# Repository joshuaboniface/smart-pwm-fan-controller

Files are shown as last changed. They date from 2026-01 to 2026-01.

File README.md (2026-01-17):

# Smart PWM Fan Controller v1.x

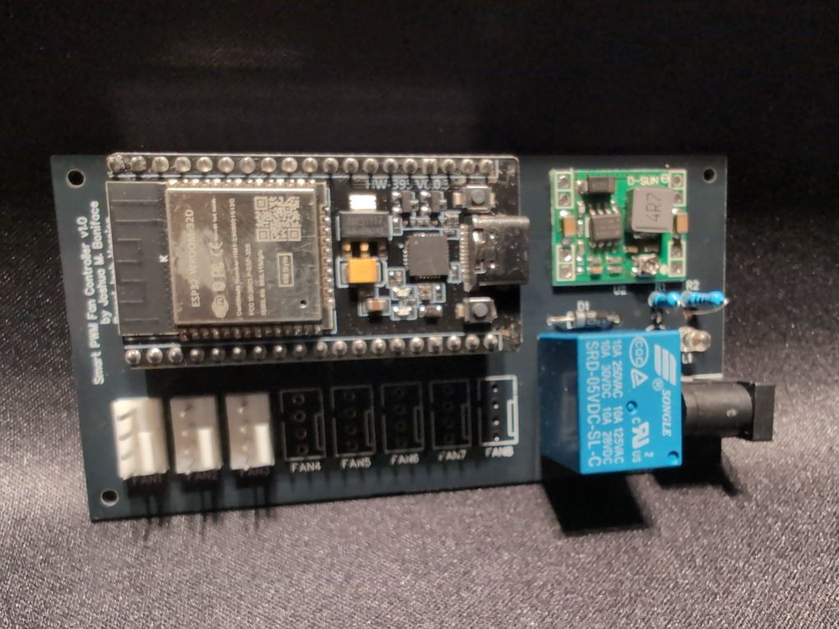
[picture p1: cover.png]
Fan Controller


The Smart PWM Fan Controller is a 4-pin 12V PWM PC fan controller (as the name implies) based on the ESP32 HW-395 form-factor and running ESPHome, and powered by a 12VDC barrel jack or 12V EPS (CPU) connector (ensure you pick the right board design).

It can connect up to 8 fans directly, with the following functionality:

 * Bank on/off via relay.
 * Bank PWM control (0-100%) via ESP32 GPIO.
 * Individual fan RPM monitoring (2PPM) via ESP32 PCNT.
 * Bank fault detection via settable fan count and RPM detection (an expected-present fan with 0 RPM while on is a fault).

The PCB design details and assembly instructions can be found [in /board](board/) and on [OSHWLab](https://oshwlab.com/joshuaboniface/microenv-2-0).

For full details, [please see my blog post on the project](https://www.boniface.me/posts/smart-pwm-fan-controller).

## Parts List

**Note:** All prices are $CAD, as of May 2025, excluding shipping, sales, and bulk discounts beyond those indicated.

**Note:** For AliExpress item links marked `*`, ensure you select the correct device; multiple different models share the page.

**Note:** Several pieces came as part of larger variety kits, so individual prices may not be completely accurate.

| Qty | PCB ID(s) | Component | Cost | Links |
|---|---|---|---|---|
| 1 | N/A | Custom PCB (JLC) | $0.50 ($5.00/10) | [GitHub](https://github.com/joshuaboniface/esphome-pwm-fan-controller) |
| 1 | U1 | ESP32 HW-395 | $6.67 | [AliExpress](https://www.aliexpress.com/item/1005006019875837.html)* |
| 8 | FANX | 4-pin fan header | $0.21 ($1.02/5) | [AliExpress](https://www.aliexpress.com/item/1005007499957251.html) |
| 1 | U2 | MP1584EN DC-DC converter  | $1.34 ($13.99/10) | [Amazon](https://www.amazon.ca/dp/B07THSDWHX) (variable output) |
| 1 | U4 | SRD-05VDC-SL-C relay | $1.52 ($18.16/12) | [Amazon](https://www.amazon.ca/dp/B098JHY5TP) |
| 1 | U3 | DC barrel jack | $0.98 ($9.79/10) | [Amazon](https://www.amazon.ca/dp/B011HFLKI2) |
| 2 | R1/R2 | 1kΩ resistor (1%) | $0.06 ($10.99/200) | [Amazon](https://www.amazon.ca/dp/B096PK4XN5) |
| 1 | D1 | 1N4004 diode | $0.07 ($20.99/300) | [Amazon (kit)](https://www.amazon.ca/dp/B07YK3XMQQ) |
| 1 | Q1 | BC337 transistor | $0.06 ($12.13/200) | [Amazon (kit)](https://www.amazon.ca/dp/B07X62PBMH) |
| 1 | L1 | 3mm LED | $0.05 ($15.99/350) | [Amazon (kit)](https://www.amazon.ca/dp/B073GRZNRL) |
| 2 | N/A | 2.54mm 1x19 female header | $0.31 ($3.14/10) | [AliExpress](https://www.aliexpress.com/item/4001198421663.html)* |
| **T** | | | $13.30 | |

# Contributing

If you wish to contribute to the MicroEnv project, please open a pull request in this repository. All pull requests will be carefully reviewed before inclusion, as we are extremely selective about what we modify. Note that any signifiant logical changes should also be compatible with the SuperSensor, and changes from that project will be occasionally integrated here.

Please ensure you target the correct branch(es) for your changes. Currently we are supporting both `v1.x` and `v2.x` in software as noted above, and there is no `master`/`main` branch. This support of both `v1.x` and `v2.x` means a 1-to-1 correlation of functionality between those two versions, so any PR to one will be back- or forward-ported to the other, and your changes(s) must be compatable with both.

Any changes must be **globally applicable to all users** of the project; if you wish to maintain your own customizations that are only applicable for yourself, please fork the project and adjust your package import URL accordingly.

"AI" (LLM) contributions are not prohibited, but you - a human - **must** at least review, reformat, and test the changes yourself before submitting them. Obviously pure-LLM-generated PRs that do not function, mangle formatting or functionality, or otherwise clearly have no human review will be rejected with prejudice. This extends to the PR body itself: write in your own words, not the output of an LLM, and if you can't concisely sumarize the changes yourself, then we're not interested in them.

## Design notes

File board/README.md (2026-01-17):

# Smart PWM Fan Controller v1.x Board Designs

This is a collection of [EasyEDA](https://easyeda.com/) schematics and board desgins for the Smart PWM Fan Controller v1.x's components.

You can import the design definition files (`*.easyeda.json`) directly into EasyEDA via "File" -> "Open" -> "EasyEDA". The schematic is provided for reference in both EasyEDA and SVG formats; if you just wish to manufacture the boards, you only need to import the board definitions, then via "Fabrication" -> "One-click Order PCB/SMT" complete the order at [JLCPCB](https://jlcpcb.com). We order all boards in a black silkscreen with all other options as default.

You can also see the designs directly on [OSHWLab here](https://oshwlab.com/joshuaboniface/smart-pwm-fan-controller-1-0).

The board design and images in this folder are © 2025 [Joshua M. Boniface](https://www.boniface.me) and licensed under the [Creative Commons Attribution-ShareAlike (BY-SA) 4.0](LICENSE) license.

## Schematic

The schematic is visible here in SVG format, and also as an EasyEDA definition in [schematic.easyeda.json](schematic.easyeda.json).

Design schematic

The individual parts can be found, with their labels (`R1`, etc.) in the [main README parts list](https://github.com/joshuaboniface/smart-pwm-fan-controller/?tab=readme-ov-file#parts-list).

## Board

Smart PWM Fan Controller v1.x board

This is the main board of the controller which contains all components.

The board is single-sided; there are no components on the reverse side, though most components are through-hole.

## Assembly

**NOTE:** The assembly step ordering is **extremely important** if you are using a **variable 12VDC-to-5VDC converter**! You must calibrate it before attaching most components, or can risk frying them.

Assembly is fairly straightforward aside from the ordering. Most of the soldering should be done with a standard soldering iron, though hot air or a hotplate can make attaching the MP1584EN easier.

1. Clean all PCBs thoroughly with isopropyl alcohol and paper towel.

2. If using hot air or a hotplate for the MP1584EN, apply a liberal amount of solder paste to each pad.

3. Solder the MP1584EN onto the board using the desired method.

4. Solder the barrel jack (or Molex connector) onto the board.

5. Perform calibration of the MP1584EN. Plug in a 12VDC source, and turn the adjustment screw until a multimeter on the output ports reads ~5.05VDC.

6. Solder the remaining components onto the board. We tend to start with the smaller components (Q1, L1, R1/R2, D1) then move onto the larger components (U4, U1, FANX).

5. Perform electrical continuity tests to ensure there are no stray bridges or faulty connections.

The Smart PWM Fan Controller is now fully assembled and ready for final testing/provisioning.

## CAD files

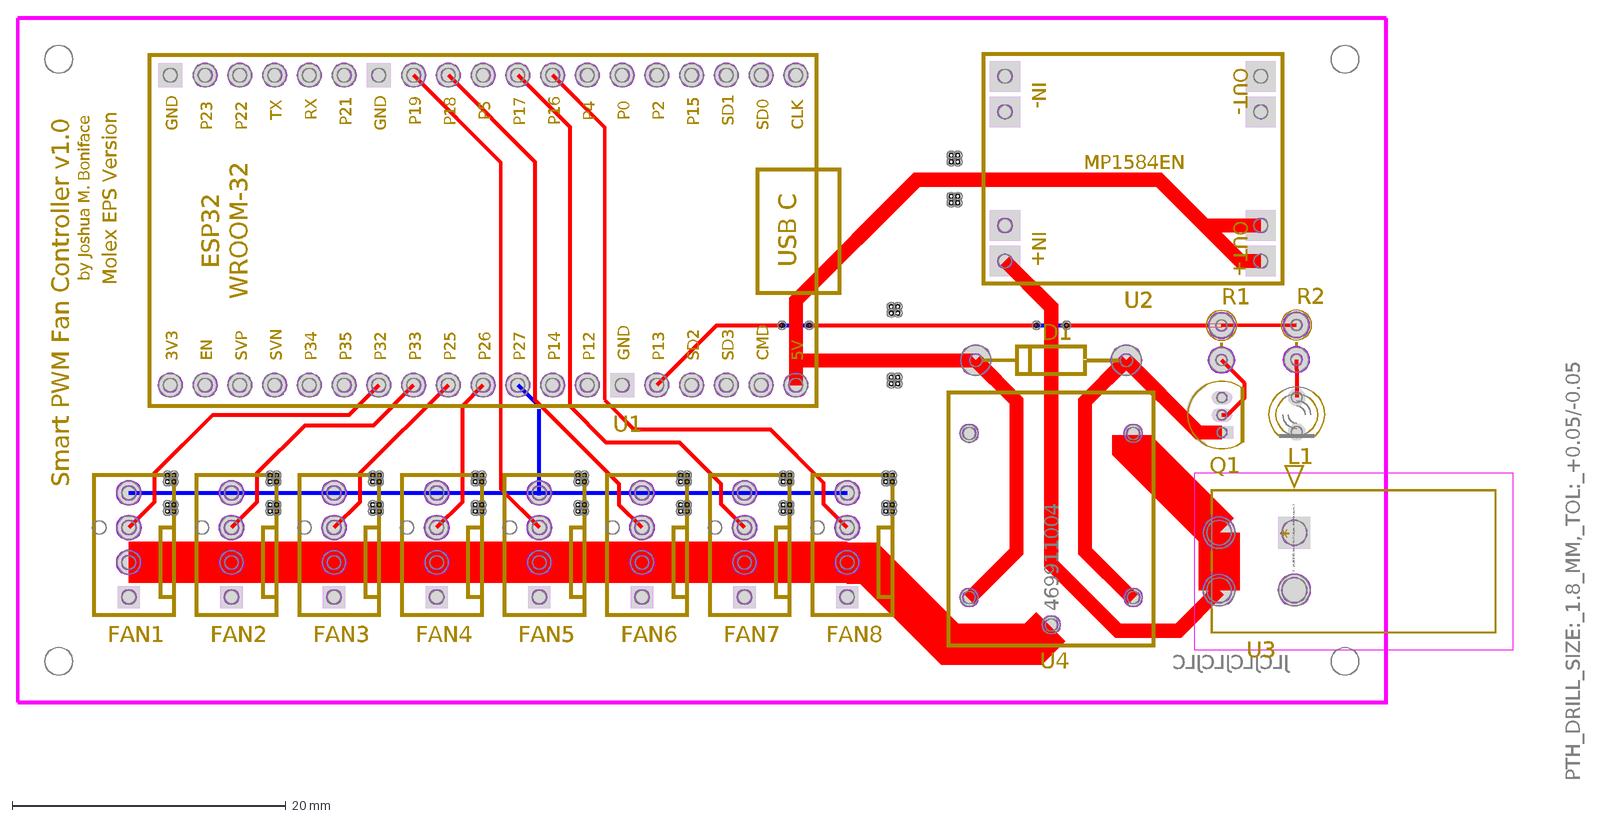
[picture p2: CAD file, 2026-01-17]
board/fan-controller-molex-eps.dxf
JLCJLCJLCJLC
Smart PWM Fan Controller v1.0
by Joshua M. Boniface
Molex EPS Version
U3
Copyright 2021 Accelerated Designs. All rights reserved.
*
469911004
PTH_DRILL_SIZE:_1.8_MM,_TOL:_+0.05/-0.05
D1
L1
Q1
R1
R2
U2
OUT-
OUT+
IN-
IN+
MP1584EN
U4
U1
3V3
EN
SVP
SVN
P34
P35
P32
P33
P25
P26
P27
P14
P12
GND
P13
SD2
SD3
CMD
5V
P23
P22
TX
RX
P21
P19
P18
P5
P17
P16
P4
P0
P2
P15
SD1
SD0
CLK
ESP32
WROOM-32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

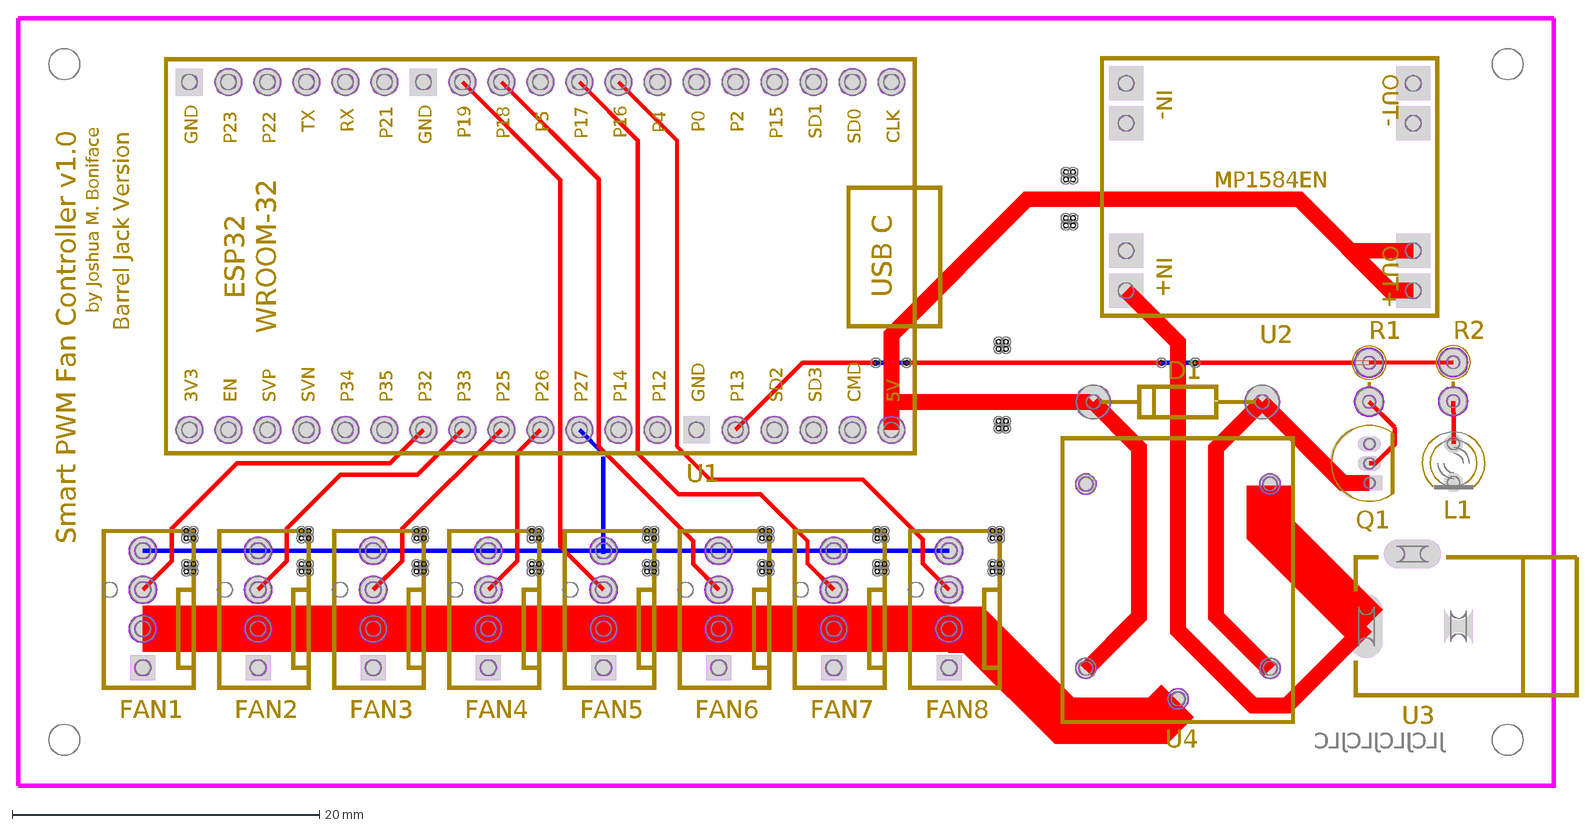
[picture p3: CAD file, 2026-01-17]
board/fan-controller-barrel-jack.dxf
JLCJLCJLCJLC
Barrel Jack Version
by Joshua M. Boniface
Smart PWM Fan Controller v1.0
D1
L1
Q1
R1
R2
U2
OUT-
OUT+
IN-
IN+
MP1584EN
U3
U4
U1
3V3
EN
SVP
SVN
P34
P35
P32
P33
P25
P26
P27
P14
P12
GND
P13
SD2
SD3
CMD
5V
P23
P22
TX
RX
P21
P19
P18
P5
P17
P16
P4
P0
P2
P15
SD1
SD0
CLK
ESP32
WROOM-32
USB C
FAN1
FAN2
FAN3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

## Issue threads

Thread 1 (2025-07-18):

Gerber schematic files

lubbertkramer, 2025-07-18:
Hi,

i would like to build your PCB but i don't see the GERBER Schematic files that i could add to PCBWay to let the board be builded. Are they available?

Thanks!

lubbertkramer, 2025-07-18:
Sorry oversaw the EasyAda files, made the gerber files myself. Thanks!

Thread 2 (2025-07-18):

Schematics file to add temperature sensor

lubbertkramer, 2025-07-18:
Hi,

could you also share the schematics file so i can alter your board to add a temperature sensor? I would like to use this board with 12v fans in the cabinet (PS5 / xbox) but would like to add a temperature sensor to it.

Thanks!

nebriv, 2025-08-27:
@lubbertkramer would also love to see that, any chance you have a fork?

lubbertkramer, 2025-08-27:
If @joshuaboniface has no problems with it i can share it with him so he can publish it here combined after my order has been delivered and i have checked its working as i expect it will be :)

Closed 2025-07-18.

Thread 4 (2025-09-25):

Ordering the PCB help

thomasgebets, 2025-09-25:
Hi i found your blog on the ESP32 PWM Controller and would like to replicate.
Unfortunately, i'm struggling with ordering the PCB since i have never done it and jlcpcb asks me for a gerber file?

Did you need such a file to order, could you maybe provide your order details such as pcb type etc?

Thanks for the help, appreciate it!

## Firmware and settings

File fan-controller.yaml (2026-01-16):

---

###############################################################################
# Smart PWM Fan Controller v1.0 ESPHome configuration
###############################################################################
#
#    Copyright (C) 2025 Joshua M. Boniface <joshua@boniface.me>
#
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
###############################################################################

esphome:
  name: fan-controller
  name_add_mac_suffix: true
  friendly_name: "Fan Controller"
  project:
    name: joshuaboniface.fan-controller
    version: "1.0"
  on_boot:
    priority: 200
    then:
      - script.execute:
          id: set_fan_speed
          value: !lambda 'return id(fan_speed);'

dashboard_import:
  package_import_url: github://joshuaboniface/smart-pwm-fan-controller/fan-controller.yaml@master

esp32:
  board: esp32dev
  framework:
      type: esp-idf

preferences:
  flash_write_interval: 15sec

logger:
  level: VERBOSE
  baud_rate: 115200

api:
  reboot_timeout: 15min

ota:
  platform: esphome

web_server:
  port: 80

captive_portal:

mdns:
  disabled: false

wifi:
  ap: {}
  domain: ""
  output_power: 8.5dB
  reboot_timeout: 15min
  power_save_mode: none

globals:
  - id: fan_speed
    type: float
    restore_value: true
    initial_value: '100.0'

  - id: attached_fans
    type: int
    restore_value: true
    initial_value: '0'

script:
  - id: set_fan_speed
    mode: single
    then:
      - lambda: |-
          id(fan_pwm_output).set_level(id(fan_speed) / 100.0);

number:
  - platform: template
    name: "Fan Speed"
    id: fan_speed_setter
    unit_of_measurement: "%"
    min_value: 0
    max_value: 100
    step: 1
    set_action:
      then:
        - lambda: |-
            ESP_LOGD("fan_speed", "Setting fan speed to %.1f%%", x);
            id(fan_speed) = x;
            id(fan_pwm_output).set_level(x / 100.0);
    lambda: |-
      return id(fan_speed);

  - platform: template
    name: "Attached Fans"
    id: attached_fans_setter
    icon: mdi:fan-auto
    min_value: 0
    max_value: 8
    step: 1
    set_action:
      then:
        - lambda: |-
            id(attached_fans) = x;
    lambda: |-
      return id(attached_fans);

switch:
  - platform: gpio
    name: "Fan Power"
    id: fan_power
    icon: mdi:fan
    pin: GPIO13

  - platform: template
    name: "Show Total in Fan Status"
    id: show_total_fans
    icon: mdi:ab-testing
    optimistic: true
    restore_mode: RESTORE_DEFAULT_OFF

output:
  - platform: ledc
    id: fan_pwm_output
    pin: GPIO27

button:
  - platform: restart
    name: "ESP32 Restart"
    icon: mdi:power-cycle
    entity_category: diagnostic

text_sensor:
  - platform: template
    name: "Fan Fault"
    icon: mdi:fan-alert
    update_interval: 30s
    lambda: |-
      if (!id(fan_power).state) return std::string("Off");
      if (id(active_fan_count).state < id(attached_fans)) return std::string("Fault");
      return std::string("OK");

  - platform: template
    name: "Active Fans"
    id: active_fans
    icon: mdi:numeric
    update_interval: 5s
    lambda: |-
      if (id(show_total_fans).state) return std::to_string(int(id(active_fan_count).state)) + " / " + std::to_string(id(attached_fans));
      return std::to_string(int(id(active_fan_count).state));

  - platform: version
    name: "ESPHome Version"
    entity_category: diagnostic

  - platform: wifi_info
    ip_address:
      name: "WiFi IP Address"
    ssid:
      name: "WiFi SSID"
    bssid:
      name: "WiFi BSSID"
    mac_address:
      name: "WiFi MAC Address"
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

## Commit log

2026-01-16 Improve fault detection off state
    Avoid basing off active fan count, which could fail if a single (or all)
    fans don't output PWM/power up. Instead base off power state, and
    increase update interval to handle initial spinups.
    [fan-controller.yaml]
2026-01-17 Improve READMEs and board details
    [fan-controller-barrel-jack.dxf, fan-controller-molex-eps.dxf]
2026-03-18 Set RESTORE_DEFAULT_OFF for fan power
    Allows fan to restore after a power outage.

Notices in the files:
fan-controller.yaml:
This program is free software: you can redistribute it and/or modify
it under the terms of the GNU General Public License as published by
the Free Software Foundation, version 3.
